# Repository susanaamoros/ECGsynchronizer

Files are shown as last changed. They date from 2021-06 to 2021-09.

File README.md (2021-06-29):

# ECGsynchronizer

Source code developed to build a simple prospective ECG-T synchronizer that generates a Transistor-Transistor-Logic (TTL) signal to be used in any TTL compatible instrument.  The system is based in an Arduino-based controller board and can be adjusted to trigger events at any phase of the cardiac cycle, or to compensate for possible instrumentation delays.

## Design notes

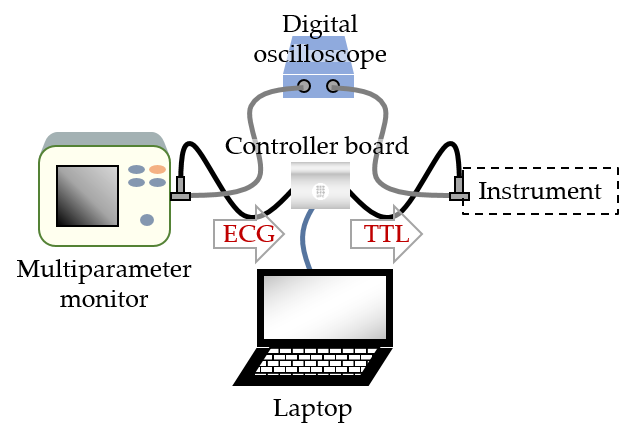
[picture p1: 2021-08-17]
ECGtoTTL/ConnectionDiagrams/ConnctionDiagram.png

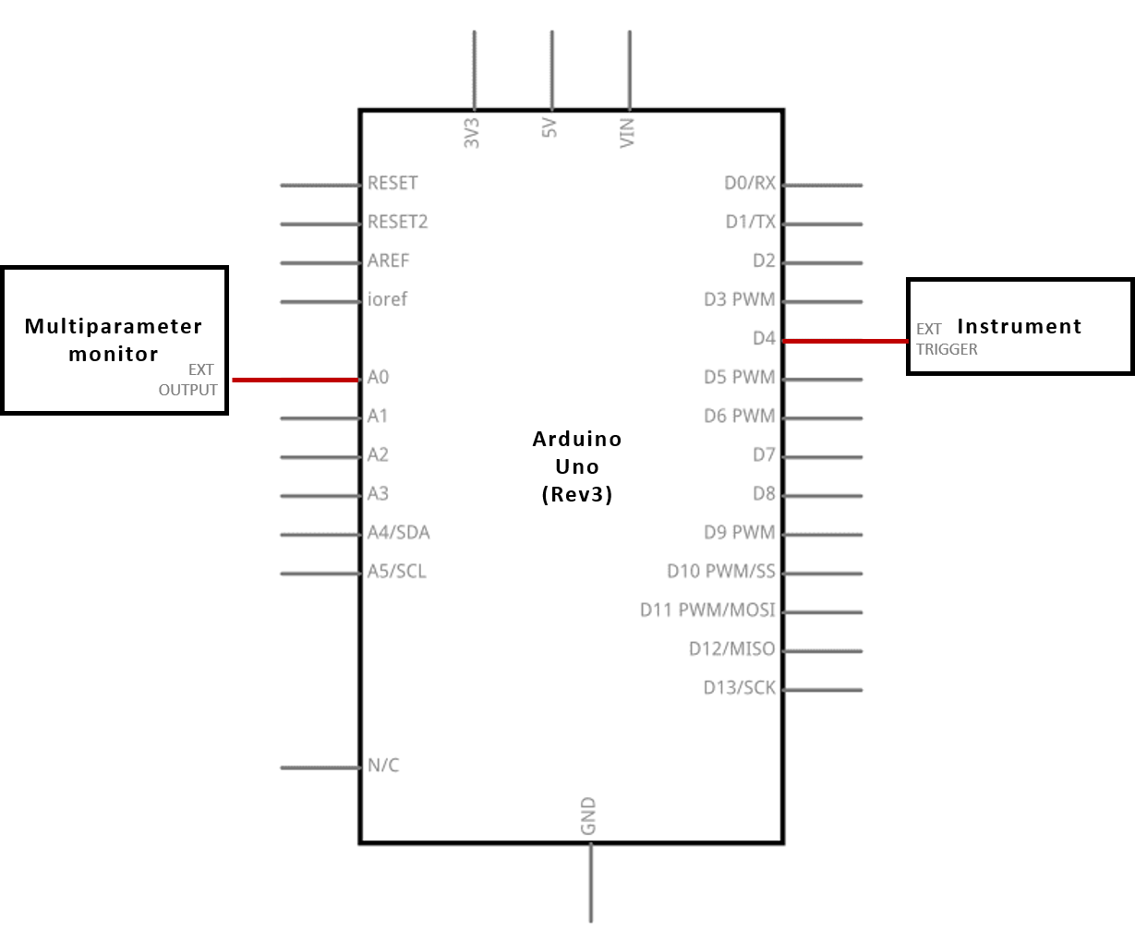
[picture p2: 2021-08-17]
ECGtoTTL/ConnectionDiagrams/ArduinoConnectionDiagram.png

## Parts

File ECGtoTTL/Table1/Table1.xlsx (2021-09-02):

STAGE | SOURCE | TRACE | # CYCLES | # FP / # R-WAVES (%) | # FN / # R-WAVES (%) | ERROR (%)
Adjustment | Demo | D001 | 20 | 0 | 0 | 0
 |  | D002 | 50 | 0 | 0 | 0
 | Human | P101 | 64 | 0 | 9.38 | 9.38
 |  | P102 | 60 | 0 | 6.67 | 6.67
 |  | P103 | 61 | 0 | 8.2 | 8.2
 |  | P104 | 59 | 1.69 | 10.17 | 11.86
 |  | P105 | 67 | 1.49 | 17.91 | 19.4
 |  | P106 | 65 | 0 | 1.54 | 1.54
 |  | P107 | 64 | 4.69 | 0 | 4.69
 |  | P108 | 63 | 0 | 0 | 0
 |  | P109 | 66 | 0 | 0 | 0
 |  | P110 | 13 | 0 | 0 | 0
 |  | P111 | 64 | 0 | 0 | 0
 |  | P112 | 67 | 0 | 0 | 0
Testing | Swine | S101 | 136 | 0.74 | 0 | 0.74
 |  | S201 | 138 | 0.72 | 0 | 0.72
 |  | S202 | 137 | 0.73 | 0 | 0.73
 |  | S203 | 134 | 0 | 0 | 0
 |  | S204 | 136 | 0 | 0 | 0
 |  | S301 | 221 | 0 | 1.81 | 1.81
 |  | S302 | 159 | 0 | 0.63 | 0.63

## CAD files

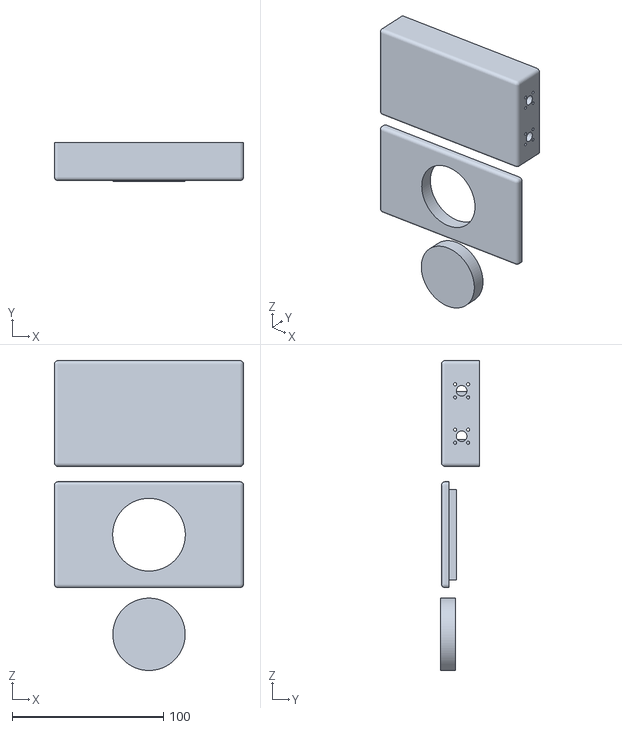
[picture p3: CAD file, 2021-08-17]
ECGtoTTL/ArduinoCase/ArduinoCase.stl
125.0 x 25.8 x 204.6

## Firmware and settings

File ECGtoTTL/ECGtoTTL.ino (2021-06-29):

// Steps to adjust the threshold value:
// 1. Set-up the Heart Rate (beats/min) you expect to work with
//    in the ECG parameters section
// 2. Adjust the transformation you want to perform during 1 period
//    in the Code variables section, x variable (log10(final value) - log10(max value))

// Input and Output pins
int inputPin = A0; // Pin where the ECG will be read
int outputPin = 4; // Pin where the TTL will be generated

// ECG parameters
float HeartRate = 60; // HeartRate in beats/min

// Code variables
int analogValue[2]; // Variable to store 2 ECG samples
int der1Value = 0; // Variable to store the der between the 2 ECG samples
float threshold = 10; // Variable to trigger the HIGH level of the TTL
int SamplRate = 1 / (5.26 * 1E-3); // dt (ms) between consecutive samples from the ECG significantly reduces the SamplRate
//float x = (1 - pow(10, (log10(17) - log10(23)) / (SamplRate*HeartRate / 60))); // REAL ECG
float x = (1 - pow(10, (log10(23) - log10(30)) / (SamplRate*HeartRate / 60))); // DEMO ECG

// Time variables
// Delays
int dtMultiParam = 25; // Delay (ms) introduced by the multi-parametric
int dt = 5; // Time distance between consecutive samples (ms)
// Millis
unsigned long t0 = 0;
unsigned long t00 = 0;
unsigned long tTTL = 0;
unsigned long Tms = 0;
unsigned long T = 0;

void setup() {
  Serial.begin(9600);
  pinMode(outputPin, OUTPUT);
  pinMode(inputPin, INPUT);
}

void loop() {
  // Store when the new iteration starts
  unsigned long t = millis();

  // Return TTL value to 0 V if it has been HIGH for more than 25 ms
  if ( t - tTTL >= 25) {
    digitalWrite(outputPin, LOW);
  }

  // Acquire two samples at dt (ms) from each other
  analogValue[0] = analogRead(A0);
  delay(dt);
  analogValue[1] = analogRead(A0);

  // Compute the difference between them
  der1Value = analogValue[1] - analogValue[0];

  // Compute the heart rate & update the threshold
  if (der1Value > threshold && t - t0 > 20) {
    t00 = t0;
    t0 = millis();
    Tms = t0 - t00; // T (ms)
    T = 60 / (Tms * 1E-3); // Heart rate (beats/min)
    Serial.print("Heart rate: "); Serial.println(T);
    //Serial.print("B:"); Serial.println(threshold);
    threshold = der1Value;
    //Serial.print("A:"); Serial.println(threshold);
  } else {
    threshold = threshold * (1 - x);
  }

  // Generate the TTL output signal
  if ( t - t0 > Tms - dtMultiParam) {
    tTTL = millis();
    digitalWrite(outputPin, HIGH);
  }
}
